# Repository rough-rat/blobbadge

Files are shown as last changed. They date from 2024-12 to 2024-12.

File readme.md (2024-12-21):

# Blobbadge

This is a backlight badge. It charlieplexes LEDs with PY32F002.

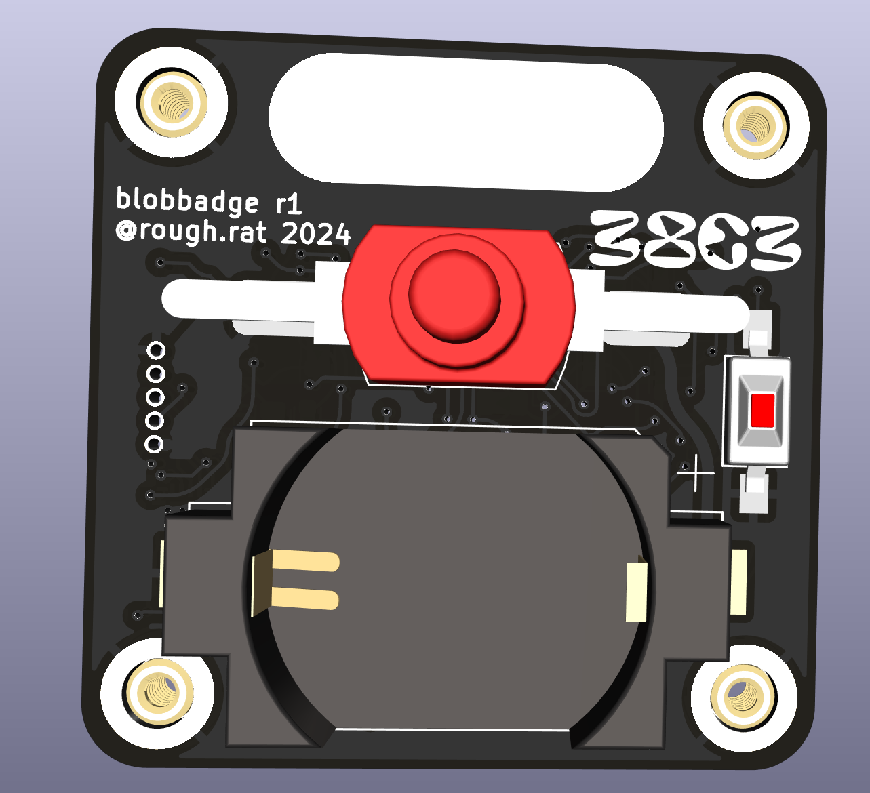
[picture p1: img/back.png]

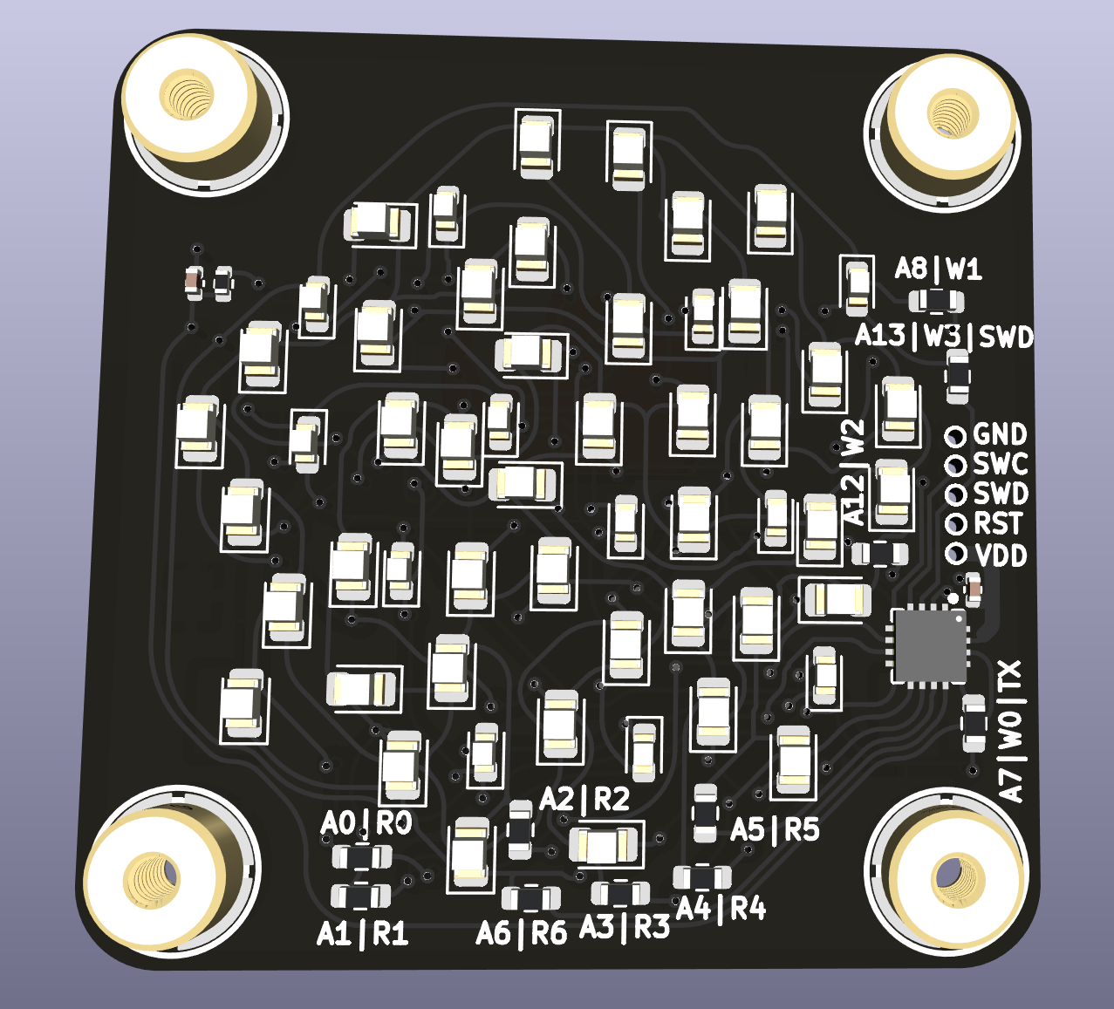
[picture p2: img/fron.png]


## IRL

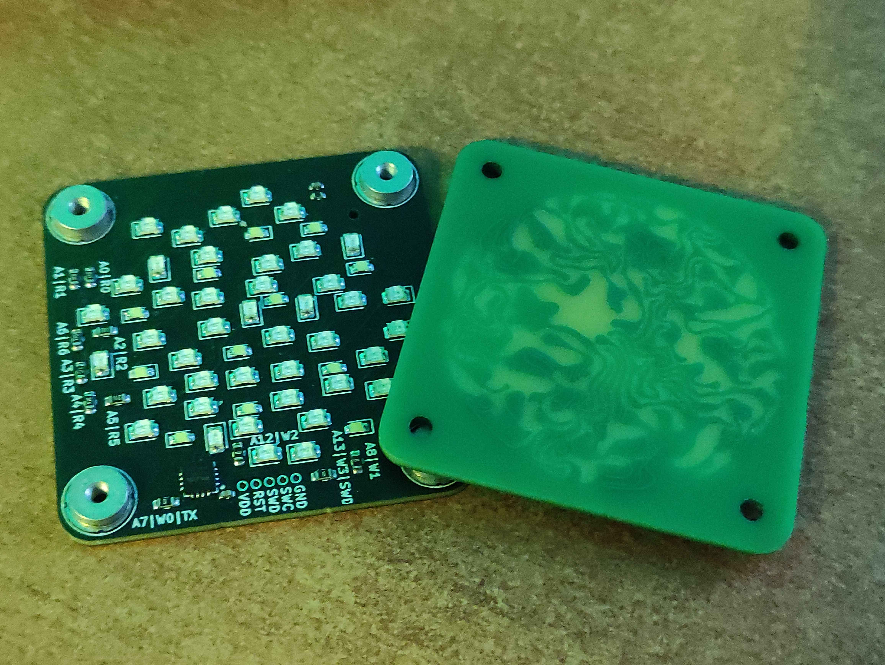
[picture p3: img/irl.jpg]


The prototype front has been made as green, to speed up / optimize the development.



Proof of concept firmware, freshly rewritten in rust

https://github.com/rough-rat/blobbadge-rs

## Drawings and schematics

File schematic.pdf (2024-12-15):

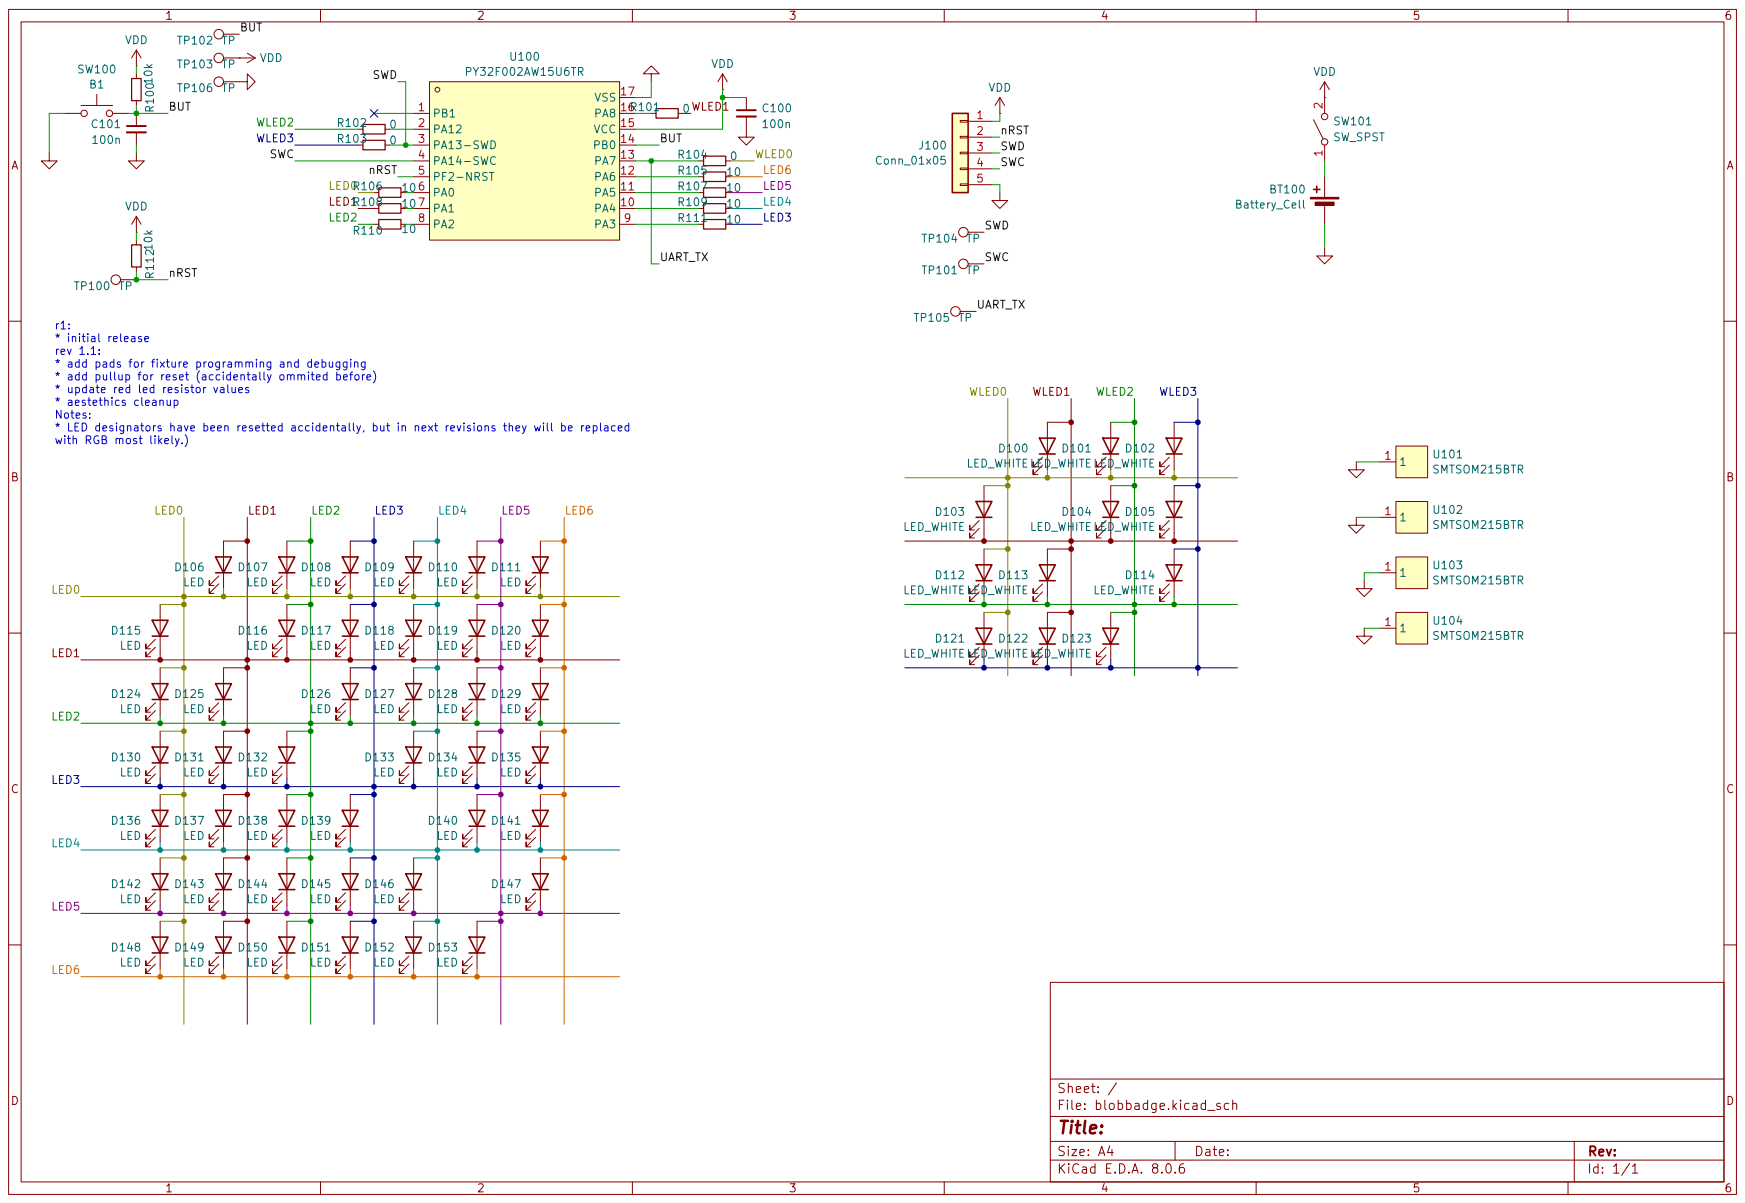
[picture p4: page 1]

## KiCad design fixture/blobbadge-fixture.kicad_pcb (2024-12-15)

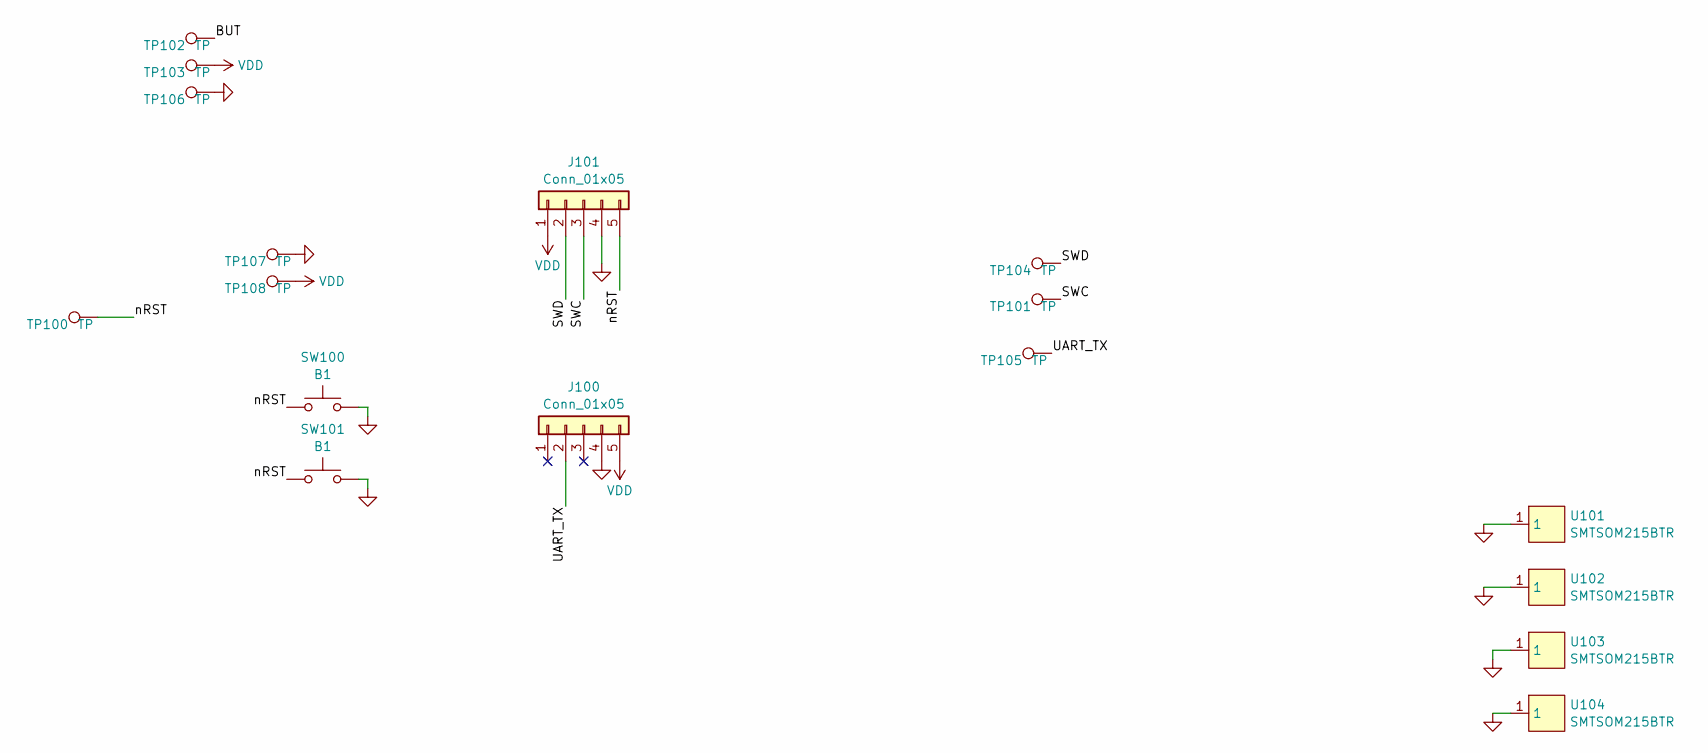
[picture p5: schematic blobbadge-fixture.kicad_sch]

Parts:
J100, J101: Conn_01x05; PinHeader_1x05_P2.54mm_SMD_flat
SW100, SW101: B1; SW_SPST_FSMSM; LCSC DNP
TP100, TP101, TP102, TP103, TP104, TP105, TP106, TP107, TP108: TP; TestPoint_THTPad_D4.0mm_Drill2.0mm; LCSC DNP
U101, U102, U103, U104: SMTSOM215BTR; SMD_BD5.6-D3.6; LCSC C5301777

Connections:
/BUT: TP102.1
/SWC: J101.3, TP101.1
/SWD: J101.2, TP104.1
/UART_TX: J100.2, TP105.1
/nRST: J101.5, SW100.1, SW101.1, TP100.1
GND: J100.4, J101.4, SW100.2, SW101.2, TP106.1, TP107.1, U101.1, U102.1, U103.1, U104.1
VDD: J100.5, J101.1, TP103.1, TP108.1

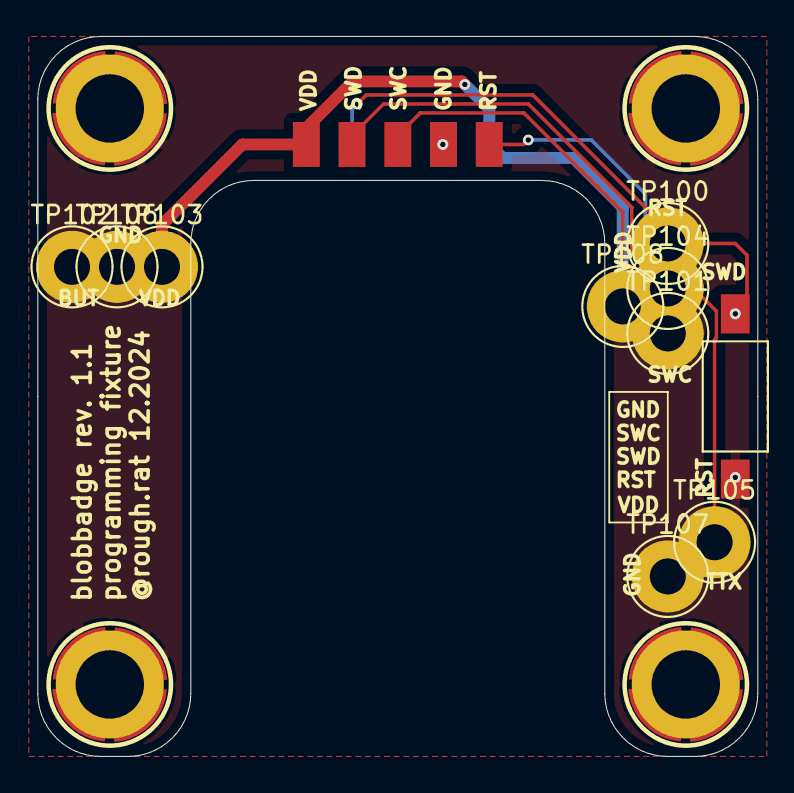
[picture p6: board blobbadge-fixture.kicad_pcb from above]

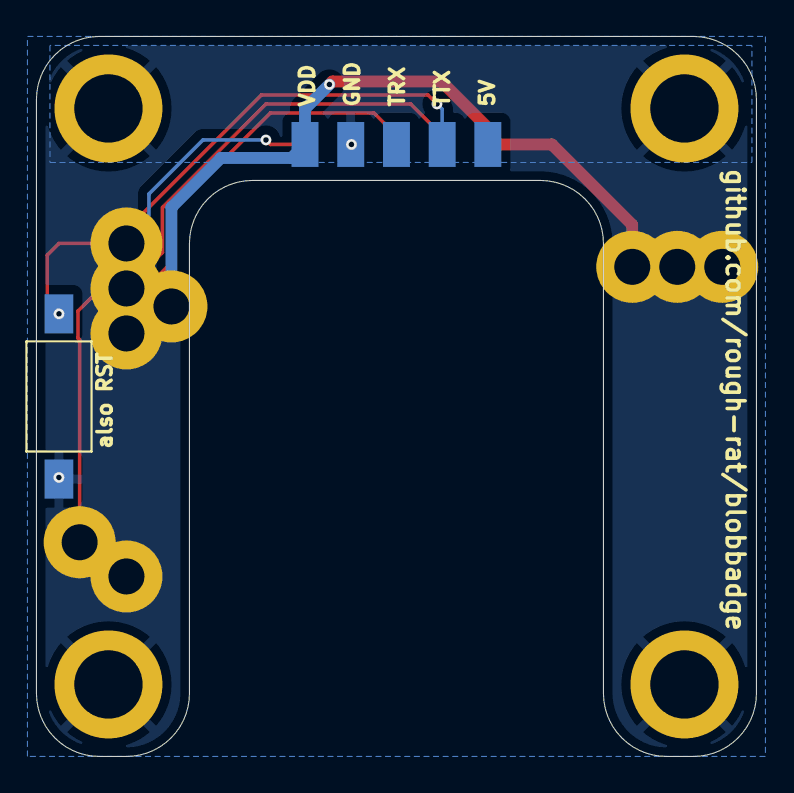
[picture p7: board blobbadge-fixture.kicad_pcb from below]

Board: 2 copper layers, 40.0 x 40.0 mm, 17 parts (2 on the bottom side), 6 nets.

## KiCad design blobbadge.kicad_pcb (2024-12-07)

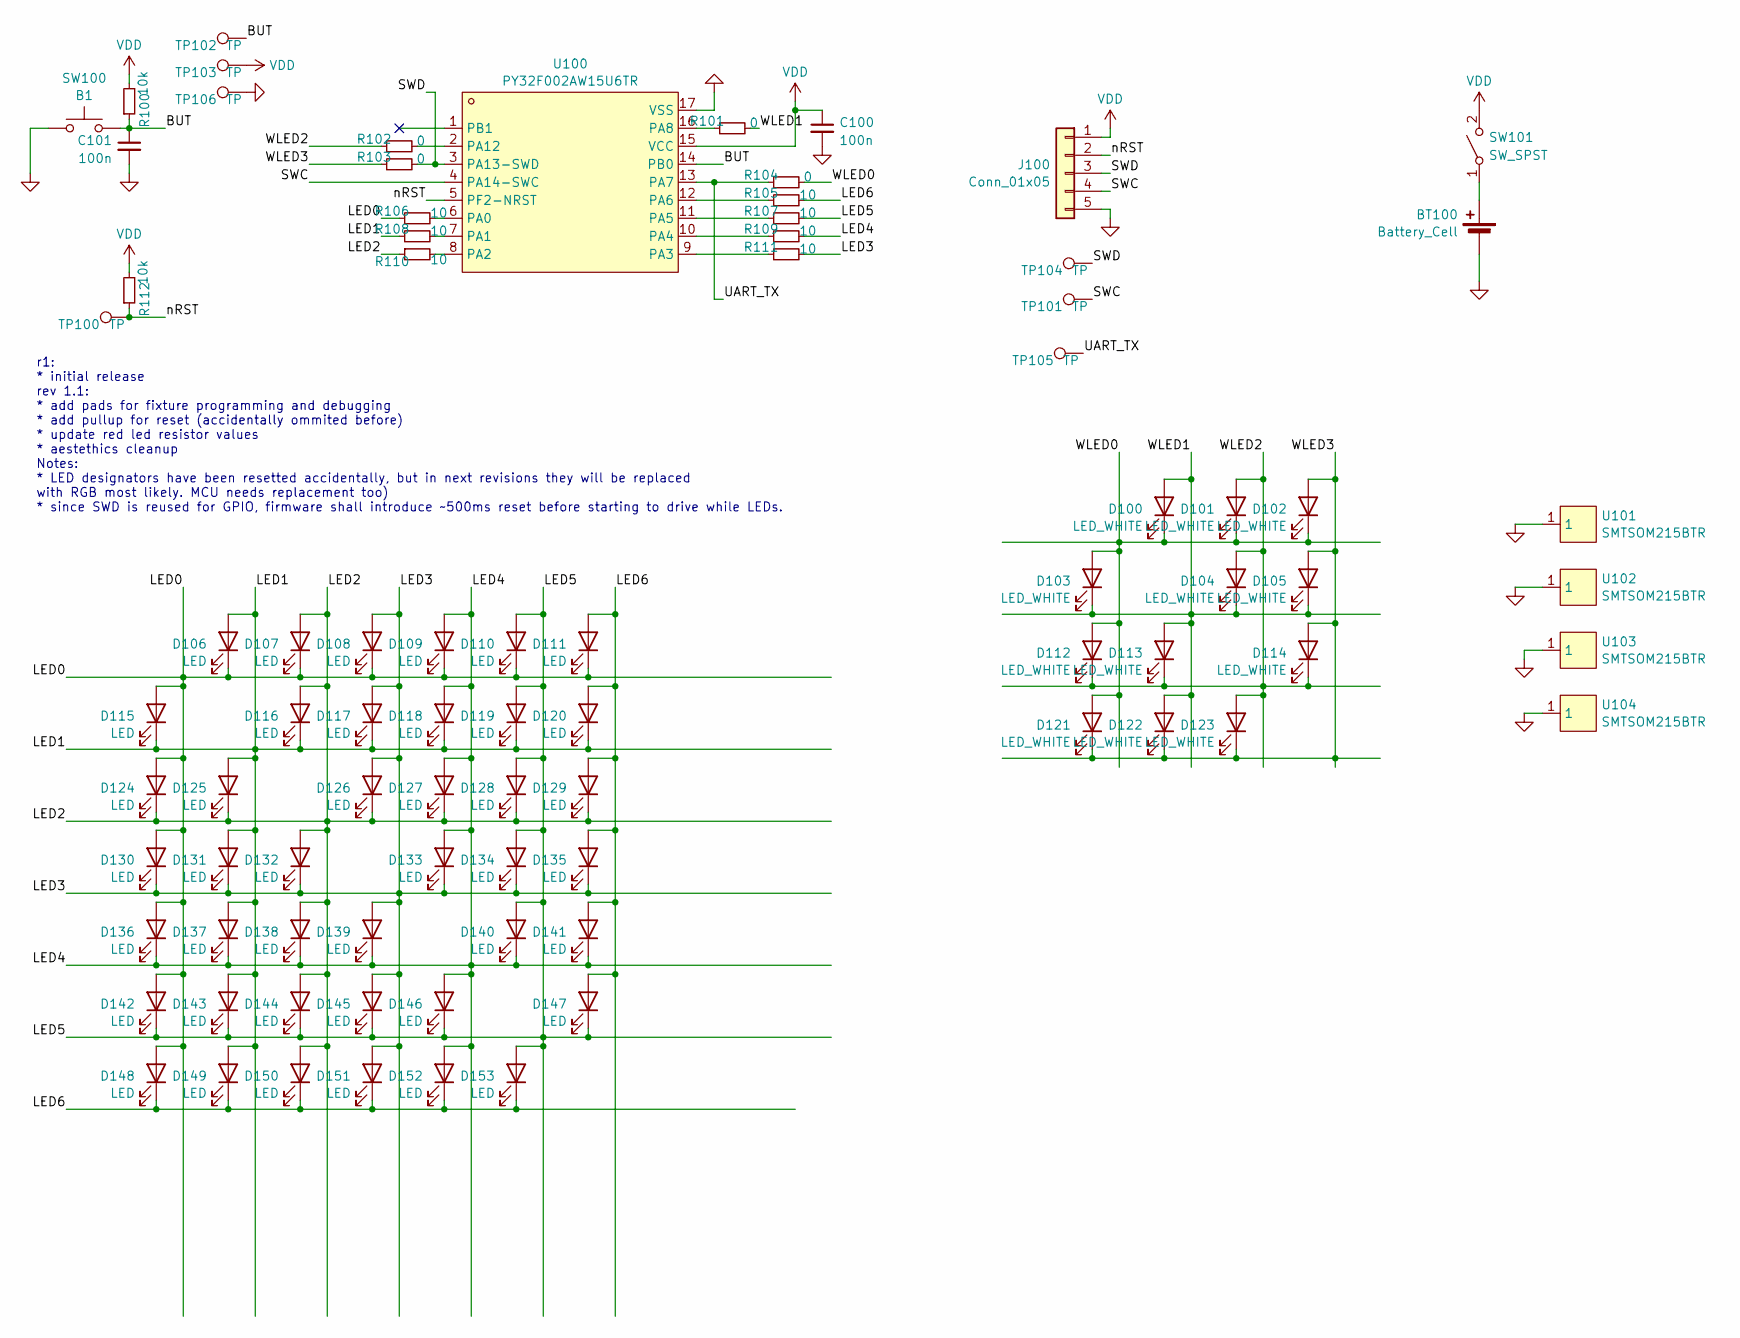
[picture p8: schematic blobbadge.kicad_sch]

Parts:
BT100: Battery_Cell; BatteryHolder_Keystone_1060_1x2032; LCSC DNP
C100, C101: 100n; C_0402_1005Metric; LCSC C1525
D100, D101, D102, D103, D104, D105, D112, D113, D114, D121, D122, D123: LED_WHITE; LED_0603_1608Metric; LCSC C34499
D106, D107, D108, D109, D110, D111, D115, D116, D117, D118, D119, D120, D124, D125, D126, D127, D128, D129, D130, D131, D132, D133, D134, D135, D136, D137, D138, D139, D140, D141, D142, D143, D144, D145, D146, D147, D148, D149, D150, D151, D152, D153: LED; LED_0805_2012Metric; LCSC C84256
J100: Conn_01x05; PinHeader_1x05_P1.27mm_Vertical; LCSC DNP
R100, R112: 10k; R_0402_1005Metric; LCSC C25744
R101, R102, R103, R104: 0; R_0603_1608Metric; LCSC C21189
R105, R106, R107, R108, R109, R110, R111: 10; R_0603_1608Metric; LCSC C22859
SW100: B1; SW_SPST_FSMSM; LCSC DNP
SW101: SW_SPST; flashlightButton; LCSC DNP
TP100, TP101, TP102, TP103, TP104, TP105, TP106: TP; TestPoint_Pad_D1.0mm; LCSC DNP
U100: PY32F002AW15U6TR; TQFN-16_L3.0-W3.0-P0.50-BL-EP1.7; LCSC C5291740
U101, U102, U103, U104: SMTSOM215BTR; SMD_BD5.6-D3.6; LCSC C5301777

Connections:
/BUT: C101.1, R100.1, SW100.2, TP102.1, U100.14 (PB0)
/LED0: D106.1 (K), D107.1 (K), D108.1 (K), D109.1 (K), D110.1 (K), D111.1 (K), D115.2 (A), D124.2 (A), D130.2 (A), D136.2 (A), D142.2 (A), D148.2 (A), R106.1
/LED1: D106.2 (A), D115.1 (K), D116.1 (K), D117.1 (K), D118.1 (K), D119.1 (K), D120.1 (K), D125.2 (A), D131.2 (A), D137.2 (A), D143.2 (A), D149.2 (A), R108.1
/LED2: D107.2 (A), D116.2 (A), D124.1 (K), D125.1 (K), D126.1 (K), D127.1 (K), D128.1 (K), D129.1 (K), D132.2 (A), D138.2 (A), D144.2 (A), D150.2 (A), R110.1
/LED3: D108.2 (A), D117.2 (A), D126.2 (A), D130.1 (K), D131.1 (K), D132.1 (K), D133.1 (K), D134.1 (K), D135.1 (K), D139.2 (A), D145.2 (A), D151.2 (A), R111.2
/LED4: D109.2 (A), D118.2 (A), D127.2 (A), D133.2 (A), D136.1 (K), D137.1 (K), D138.1 (K), D139.1 (K), D140.1 (K), D141.1 (K), D146.2 (A), D152.2 (A), R109.2
/LED5: D110.2 (A), D119.2 (A), D128.2 (A), D134.2 (A), D140.2 (A), D142.1 (K), D143.1 (K), D144.1 (K), D145.1 (K), D146.1 (K), D147.1 (K), D153.2 (A), R107.2
/LED6: D111.2 (A), D120.2 (A), D129.2 (A), D135.2 (A), D141.2 (A), D147.2 (A), D148.1 (K), D149.1 (K), D150.1 (K), D151.1 (K), D152.1 (K), D153.1 (K), R105.2
/SWC: J100.4, TP101.1, U100.4 (PA14-SWC)
/SWD: J100.3, R103.2, TP104.1, U100.3 (PA13-SWD)
/UART_TX: R104.1, TP105.1, U100.13 (PA7)
/WLED0: D100.1 (K), D101.1 (K), D102.1 (K), D103.2 (A), D112.2 (A), D121.2 (A), R104.2
/WLED1: D100.2 (A), D103.1 (K), D104.1 (K), D105.1 (K), D113.2 (A), D122.2 (A), R101.2
/WLED2: D101.2 (A), D104.2 (A), D112.1 (K), D113.1 (K), D114.1 (K), D123.2 (A), R102.1
/WLED3: D102.2 (A), D105.2 (A), D114.2 (A), D121.1 (K), D122.1 (K), D123.1 (K), R103.1
/nRST: J100.2, R112.1, TP100.1, U100.5 (PF2-NRST)
GND: BT100.2 (-), C100.2, C101.2, J100.5, SW100.1, TP106.1, U100.17 (VSS), U101.1, U102.1, U103.1, U104.1
unnamed: BT100.1 (+), SW101.1 (A)
unnamed: R106.2, U100.6 (PA0)
unnamed: R108.2, U100.7 (PA1)
unnamed: R110.2, U100.8 (PA2)
unnamed: R111.1, U100.9 (PA3)
unnamed: R109.1, U100.10 (PA4)
unnamed: R107.1, U100.11 (PA5)
unnamed: R105.1, U100.12 (PA6)
unnamed: R101.1, U100.16 (PA8)
unnamed: R102.2, U100.2 (PA12)
VDD: C100.1, J100.1, R100.2, R112.2, SW101.2 (B), TP103.1, U100.15 (VCC)

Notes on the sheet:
r1: * initial release rev 1.1: * add pads for fixture programming and debugging * add pullup for reset (accidentally ommited before) * update red led resistor values * aestethics cleanup Notes: * LED designators have been resetted accidentally, but in next revisions they will be replaced with RGB m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

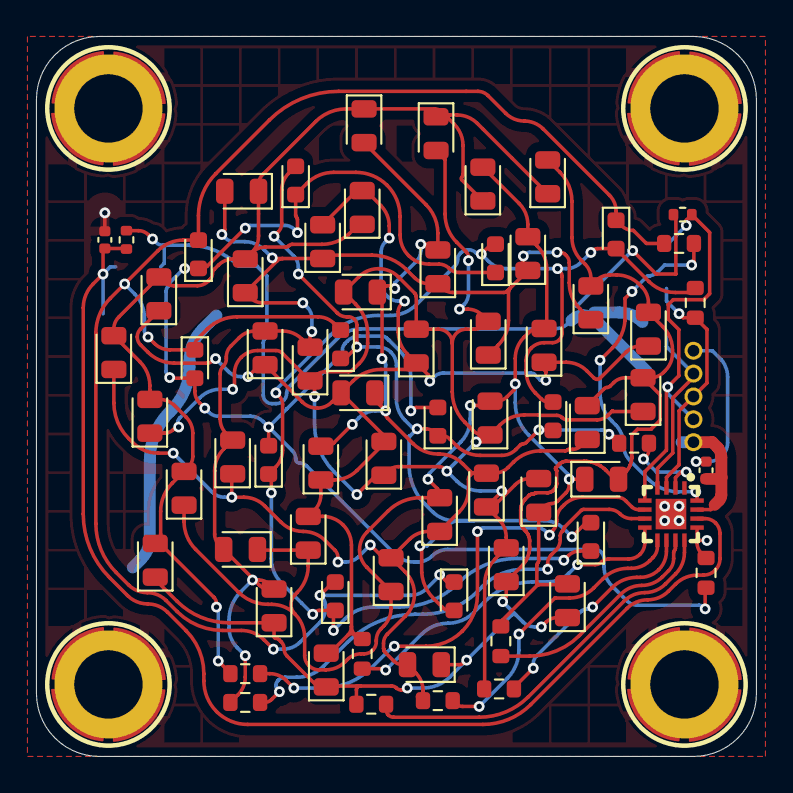
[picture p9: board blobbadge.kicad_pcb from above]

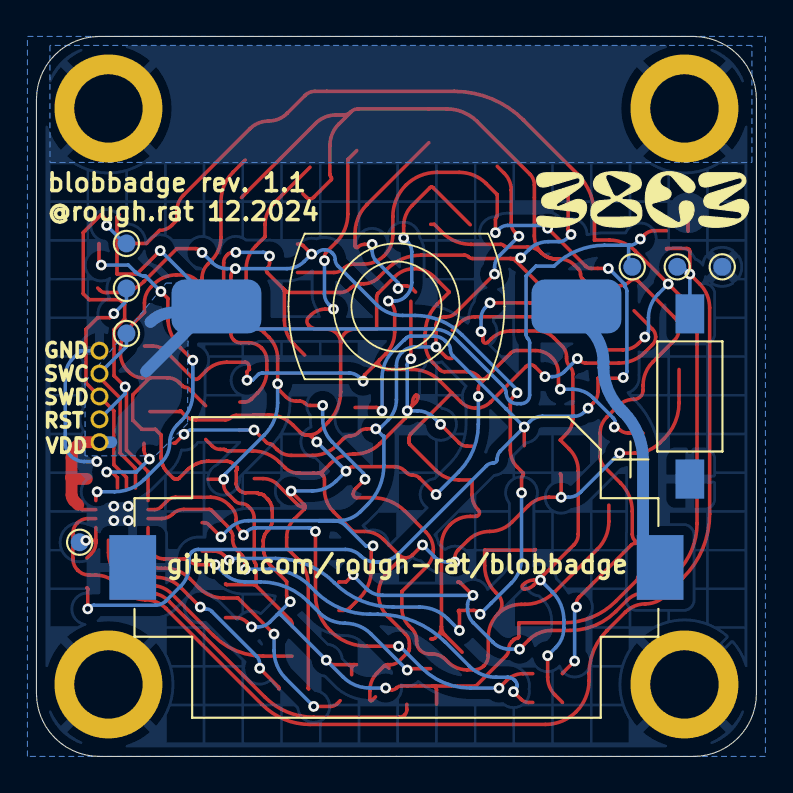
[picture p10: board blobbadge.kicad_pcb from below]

Board: 2 copper layers, 40.0 x 40.0 mm, 85 parts (10 on the bottom side), 28 nets.

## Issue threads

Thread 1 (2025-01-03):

Part List

murdarrar, 2025-01-03:
Hi, can you add a part list nedded for the Blobbadge?

murdarrar, 2025-01-11:
just found out, a 10k Resistir on the Back of the PCB did the thing

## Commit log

2024-11-24 before charlieplex remake
    [blobbadge.kicad_pcb, blobbadge.kicad_sch]
2024-11-24 add white leds, and stuff
    [blobbadge.kicad_pcb, blobbadge.kicad_sch]
2024-11-25 start route
    [blobbadge.kicad_pcb, blobbadge.kicad_sch]
2024-11-25 finish route
    [blobbadge.kicad_pcb]
2024-11-26 add order pcb and stuff
    [blobbadge-rounded.kicad_pcb]
2024-12-02 cleanup, add nice things
    [blobbadge-rounded.kicad_pcb, blobbadge.kicad_pcb, blobbadge.kicad_sch]
2024-12-02 add front
    [blobfront.kicad_pcb, blobfront.kicad_sch]
2024-12-07 add r1 order, prepare rev1.1 order
    [blobbadge.kicad_pcb, blobbadge.kicad_sch]
2024-12-15 add 2nd order and some updates
    [blobbadge.kicad_sch]
2024-12-15 add support pcbs
    [blobbadge-fixture.kicad_pcb, blobbadge-fixture.kicad_sch, blobfront.kicad_pcb]
